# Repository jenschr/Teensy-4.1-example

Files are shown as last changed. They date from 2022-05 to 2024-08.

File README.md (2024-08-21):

# Teensy 4.1 Kicad example project
Kicad files to make a custom Teensy 4.1, based on the official Teensy schematics, but exposing all pins for testing. All the 55 pins except D41 are brought out for testing. I'm using a USB Type C receptacle rather than USB Micro / A connectors. Don't forget that you'll need to buy the MKL02Z32VFG4 from PJRC for this to work. Also - be sure to scroll down on the MKL02Z32VFG4 page. There are [lots of important information there](https://www.pjrc.com/store/ic_mkl02_t4.html) on power sequencing and layout.

I'm a consultant based in Oslo/Norway, so [get in touch](https://maketronics.no/about/) if you need custom hardware based on Teensy 4.x.

## Know bugs
This version is tested and works, but the MAX1562 that I used for the USB switch has inverted polarity from what is expected. You can get around this by using the alternate part MAX1563, or something else. Only reason I went with this 4A chip is the parts shortage.

I just removed the chip and soldered bodge-wires to bypass it. This also works, but I guess it then lacks protection. I've tested with keyboard & mouse.

## Features

The board includes the required parts

- MIMXRT1062DVJ6B (Arm Cortex M7 @ 600 Mhz)
- MKL02Z32VFG4 (must be purchased from PJRC)
- W25Q64JVXGIM (8Mb spi Flash)

Optional parts (not in PJRC's design)

- [USB Type C](https://github.com/jenschr/USB-C-Connectors) for power & debug
- USB Type C host port with MAX1562 for power control
- 2.54mm pin header connections for all pins but D41
- JTAG pins broken out (not tested, but there)

Not included (from PJRC's design)
- Extra SpiFlash or PSRAM
- Ethernet

Note: the schematic symbol for the IMXRT1062 chip is really clumsy and makes the schematic more complex than required, but that's what you get if you use SamacSys Library Loader rather than making the symbol yourself.

## Picture
Here's a picture of the boards when I soldered them:

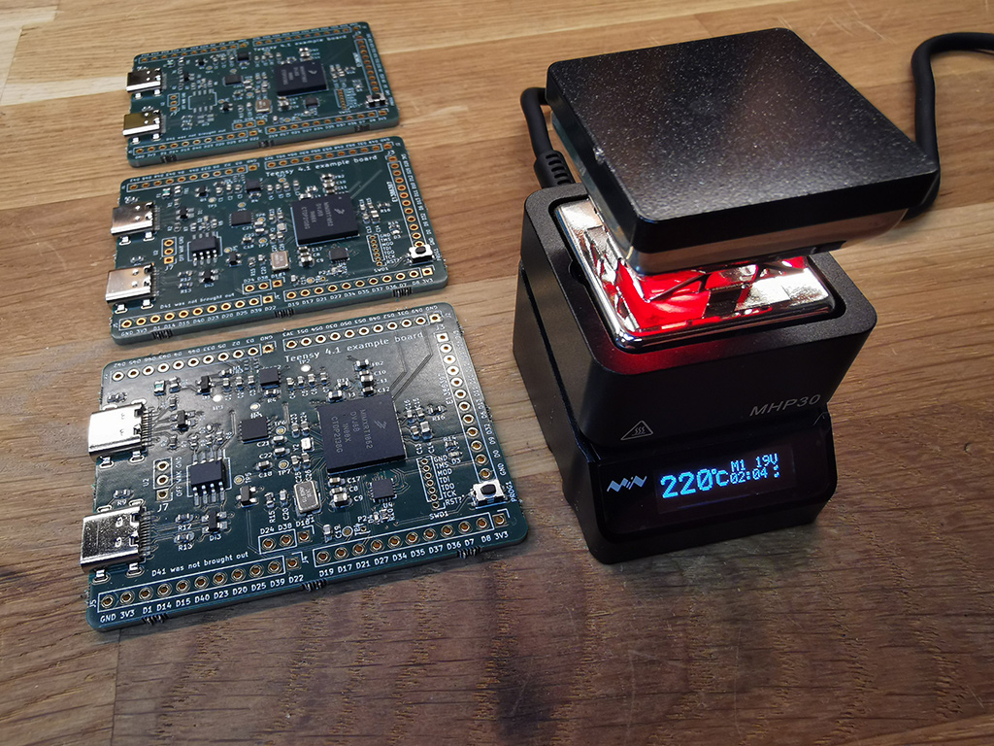
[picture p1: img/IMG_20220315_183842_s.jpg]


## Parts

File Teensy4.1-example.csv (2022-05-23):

Source: | /Volumes/Dropbox/Dropbox/Hardware/Teensy4.1-example/Teensy4.1-example.kicad_sch
Date: | 2022 March 08, Tuesday 17:22:59
Tool: | Eeschema (6.0.1-0)
Generator: | /Applications/KiCad/KiCad.app/Contents/SharedSupport/plugins/bom_csv_grouped_by_value.py
Component Count: | 80
Individual Components:
Item | Qty | Reference(s) | Value | LibPart | Footprint | Datasheet | Description | Height | MFGR | MPN | Manufacturer_Name | Manufacturer_Part_Number | Mouser Part Number | Mouser Price/Stock
 |  | C1 | 0.22uf | Device:C | Capacitor_SMD:C_0603_1608Metric | ~ |  |  | Jellybean (X7R or better) | CC0603KRX7R6BB224
 |  | C2 | 0.22uf | Device:C | Capacitor_SMD:C_0603_1608Metric | ~ |  |  | Jellybean (X7R or better) | CC0603KRX7R6BB224
 |  | C3 | 2.2uf | Device:C | Capacitor_SMD:C_0603_1608Metric | ~ |  |  | Jellybean (X7R or better) | CL10B225KP8NNNC
 |  | C4 | 0.22uf | Device:C | Capacitor_SMD:C_0603_1608Metric | ~ |  |  | Jellybean (X7R or better) | CC0603KRX7R6BB224
 |  | C5 | 10000nf | Device:C | Capacitor_SMD:C_0603_1608Metric | ~ |  |  | Jellybean (X7R or better) | 0603B103K160CT
 |  | C6 | 4.7uf | Device:C | Capacitor_SMD:C_0603_1608Metric | ~ |  |  | Jellybean (X7R or better) | CL10B475KQ8NQNC
 |  | C7 | 2.2uf | Device:C | Capacitor_SMD:C_0603_1608Metric | ~ |  |  | Jellybean (X7R or better) | CL10B225KP8NNNC
 |  | C8 | 0.22uf | Device:C | Capacitor_SMD:C_0603_1608Metric | ~ |  |  | Jellybean (X7R or better) | CC0603KRX7R6BB224
 |  | C9 | 10uf | Device:C | Capacitor_SMD:C_0805_2012Metric | ~ |  |  | Jellybean (X7R or better) | GRM21BR71A106KA73K
 |  | C10 | 0.22uf | Device:C | Capacitor_SMD:C_0603_1608Metric | ~ |  |  | Jellybean (X7R or better) | CC0603KRX7R6BB224
 |  | C11 | 10uf | Device:C | Capacitor_SMD:C_0805_2012Metric | ~ |  |  | Jellybean (X7R or better) | GRM21BR71A106KA73K
 |  | C12 | 4.7uf | Device:C | Capacitor_SMD:C_0603_1608Metric | ~ |  |  | Jellybean (X7R or better) | CL10B475KQ8NQNC
 |  | C13 | 0.22uf | Device:C | Capacitor_SMD:C_0603_1608Metric | ~ |  |  | Jellybean (X7R or better) | CC0603KRX7R6BB224
 |  | C14 | 10uf | Device:C | Capacitor_SMD:C_0805_2012Metric | ~ |  |  | Jellybean (X7R or better) | GRM21BR71A106KA73K
 |  | C15 | 4.7uf | Device:C | Capacitor_SMD:C_0603_1608Metric | ~ |  |  | Jellybean (X7R or better) | CL10B475KQ8NQNC
 |  | C16 | 10000nf | Device:C | Capacitor_SMD:C_0603_1608Metric | ~ |  |  | Jellybean (X7R or better) | 0603B103K160CT
 |  | C17 | 0.22uf | Device:C | Capacitor_SMD:C_0603_1608Metric | ~ |  |  | Jellybean (X7R or better) | CC0603KRX7R6BB224
 |  | C18 | 0.22uf | Device:C | Capacitor_SMD:C_0603_1608Metric | ~ |  |  | Jellybean (X7R or better) | CC0603KRX7R6BB224
 |  | C19 | 10pf | Device:C | Capacitor_SMD:C_0603_1608Metric | ~ |  |  | Jellybean (X7R or better) | CC0603KRX7R6BB224
 |  | C20 | 10pf | Device:C | Capacitor_SMD:C_0603_1608Metric | ~ |  |  | Jellybean (X7R or better) | CC0603KRX7R6BB224
 |  | C21 | 9pf | Device:C | Capacitor_SMD:C_0603_1608Metric | ~ |  |  | Jellybean (X7R or better) | GRM1885C1H9R0DA01D
 |  | C22 | 9pf | Device:C | Capacitor_SMD:C_0603_1608Metric | ~ |  |  | Jellybean (X7R or better) | GRM1885C1H9R0DA01D
 |  | C23 | 0.22uf | Device:C | Capacitor_SMD:C_0603_1608Metric | ~ |  |  | Jellybean (X7R or better) | CC0603KRX7R6BB224
 |  | C24 | 4.7uf | Device:C | Capacitor_SMD:C_0603_1608Metric | ~ |  |  | Jellybean (X7R or better) | CL10B475KQ8NQNC
 |  | C25 | 0.22uf | Device:C | Capacitor_SMD:C_0603_1608Metric | ~ |  |  | Jellybean (X7R or better) | CC0603KRX7R6BB224
 |  | C26 | 4.7uf | Device:C | Capacitor_SMD:C_0603_1608Metric | ~ |  |  | Jellybean (X7R or better) | CL10B475KQ8NQNC
 |  | D1 | SP0503BAHT | Power_Protection:SP0503BAHT | Package_TO_SOT_SMD:SOT-143 | http://www.littelfuse.com/~/media/files/littelfuse/technical%20resources/documents/data%20sheets/sp05xxba.pdf
 |  | D2 | LED | Device:LED | LED_SMD:LED_0402_1005Metric | ~
 |  | D3 | LED | Device:LED | LED_SMD:LED_0402_1005Metric | ~
 |  | D4 | LED | Device:LED | LED_SMD:LED_0402_1005Metric | ~
 |  | D5 | BAT54C | Diode:BAT54C | Package_TO_SOT_SMD:SOT-23 | http://www.diodes.com/_files/datasheets/ds11005.pdf
 |  | Di3 | SP0503BAHT | Power_Protection:SP0503BAHT | Package_TO_SOT_SMD:SOT-143 | http://www.littelfuse.com/~/media/files/littelfuse/technical%20resources/documents/data%20sheets/sp05xxba.pdf
 |  | F1 | Fuse | Device:Fuse | Resistor_SMD:R_0805_2012Metric | ~ |  |  | Bel Fuse Inc | 0ZCK0050FF2E
 |  | FB1 | Ferrite_Bead | Device:Ferrite_Bead | Resistor_SMD:R_0805_2012Metric | ~ |  |  | Taiyo Yuden | FBMH2012HM121-T‎
 |  | FB2 | Ferrite_Bead | Device:Ferrite_Bead | Resistor_SMD:R_0805_2012Metric | ~ |  |  | Taiyo Yuden | FBMH2012HM121-T‎
 |  | IC1 | MIMXRT1062DVJ6B | MIMXRT1062DVJ6B:MIMXRT1062DVJ6B | MIMXRT1062DVJ6B:BGA196C80P14X14_1200X1200X152 | https://www.nxp.com/docs/en/nxp/data-sheets/IMXRT1060CEC.pdf | IC MCU 32BIT EXT MEM 196MAPBGA | 1.52 |  |  | NXP | MIMXRT1062DVJ6B | 771-MIMXRT1062DVJ6B | https://www.mouser.co.uk/ProductDetail/NXP-Semiconductors/MIMXRT1062DVJ6B?qs=BJlw7L4Cy7%252B08A9rbTO5WQ%3D%3D
 |  | J1 | Conn_01x11_Male | Connector:Conn_01x11_Male | Connector_PinHeader_2.54mm:PinHeader_1x11_P2.54mm_Vertical | ~
 |  | J2 | Conn_01x11_Male | Connector:Conn_01x11_Male | Connector_PinHeader_2.54mm:PinHeader_1x11_P2.54mm_Vertical | ~
 |  | J3 | Conn_01x12_Male | Connector:Conn_01x12_Male | Connector_PinHeader_2.54mm:PinHeader_1x12_P2.54mm_Vertical | ~
 |  | J4 | Conn_01x11_Male | Connector:Conn_01x11_Male | Connector_PinHeader_2.54mm:PinHeader_1x11_P2.54mm_Vertical | ~
 |  | J5 | Conn_01x11_Male | Connector:Conn_01x11_Male | Connector_PinHeader_2.54mm:PinHeader_1x11_P2.54mm_Vertical | ~
 |  | J6 | Conn_01x03_Male | Connector:Conn_01x03_Male | Connector_PinHeader_2.54mm:PinHeader_1x03_P2.54mm_Vertical | ~
 |  | J7 | Conn_01x03_Male | Connector:Conn_01x03_Male | Connector_PinHeader_2.54mm:PinHeader_1x03_P2.54mm_Vertical | ~
 |  | L1 | 4.7uH | Device:L | Capacitor_SMD:C_0805_2012Metric | ~ |  |  |  | LQM21PN4R7MGRD
 |  | NCP692 | OnSemi NCP692, fixed version | ToyTronics2:OnSemi NCP692, fixed version | Package_DFN_QFN:DFN-6-1EP_3x3mm_P0.95mm_EP1.7x2.6mm | https://www.onsemi.com/pdf/datasheet/ncp690-d.pdf |  |  | Onsemi | NCP692MN33T2G
 |  | P2 | D26 | Connector:TestPoint | Connector_PinHeader_1.00mm:PinHeader_1x01_P1.00mm_Vertical | ~
 |  | PROG1 | SW_Push | Switch:SW_Push | ToyTronics:KMR241GLFS |  |  |  | C&K | KMR241GLFS
 |  | Q1 | Q_PMOS_GDS | Device:Q_PMOS_GDS | Package_TO_SOT_SMD:SOT-23 | ~
 |  | R1 | 5.1k | Device:R | Resistor_SMD:R_0603_1608Metric | ~ |  |  | Jellybean | RC0603FR-075K1L
 |  | R2 | 5.1k | Device:R | Resistor_SMD:R_0603_1608Metric | ~ |  |  | Jellybean | RC0603FR-075K1L
 |  | R3 | 100k | Device:R | Resistor_SMD:R_0603_1608Metric | ~
 |  | R4 | 100k | Device:R | Resistor_SMD:R_0603_1608Metric | ~
 |  | R5 | 1M | Device:R | Resistor_SMD:R_0603_1608Metric | ~
 |  | R6 | 16k | Device:R | Resistor_SMD:R_0603_1608Metric | ~ |  |  | Jellybean
 |  | R7 | 16k | Device:R | Resistor_SMD:R_0603_1608Metric | ~ |  |  | Jellybean
 |  | R8 | 1k | Device:R | Resistor_SMD:R_0402_1005Metric | ~
 |  | R9 | 1M | Device:R | Resistor_SMD:R_0603_1608Metric | ~
 |  | R10 | 1k | Device:R | Resistor_SMD:R_0402_1005Metric | ~
 |  | R11 | 100k | Device:R | Resistor_SMD:R_0603_1608Metric | ~
 |  | R12 | 56k | Device:R | Resistor_SMD:R_0603_1608Metric | ~ |  |  | Jellybean | RMCF0603FT56K0
 |  | R13 | 56k | Device:R | Resistor_SMD:R_0603_1608Metric | ~ |  |  | Jellybean | RMCF0603FT56K0
 |  | R14 | 1k | Device:R | Resistor_SMD:R_0402_1005Metric | ~
 |  | R15 | 2.2M | Device:R | Resistor_SMD:R_0603_1608Metric | ~
 |  | R16 | 100k | Device:R | Resistor_SMD:R_0603_1608Metric | ~
 |  | SWD1 | SWD | Connector:Conn_01x07_Female | Connector_PinHeader_1.27mm:PinHeader_1x07_P1.27mm_Vertical | ~
 |  | TP1 | TestPoint | Connector:TestPoint | TestPoint:TestPoint_Pad_D1.0mm | ~
 |  | TP2 | TestPoint | Connector:TestPoint | TestPoint:TestPoint_Pad_D1.0mm | ~
 |  | TP3 | TestPoint | Connector:TestPoint | TestPoint:TestPoint_Pad_D1.0mm | ~
 |  | TP4 | TestPoint | Connector:TestPoint | TestPoint:TestPoint_Pad_D1.0mm | ~
 |  | TP5 | TestPoint | Connector:TestPoint | TestPoint:TestPoint_Pad_D1.0mm | ~
 |  | TP6 | TestPoint | Connector:TestPoint | TestPoint:TestPoint_Pad_D1.0mm | ~
 |  | TP7 | TestPoint | Connector:TestPoint | TestPoint:TestPoint_Pad_D1.0mm | ~
 |  | U1 | opto_APA102-2020 | APA102:opto_APA102-2020 | USB-C-Power-tester:APA102-2020
 |  | U2 | MAX1562 | MIMXRT1062DVJ6B:MAX1562 | Package_SO:SO-8_5.3x6.2mm_P1.27mm
 |  | U3 | W25Q64JVXGIM | MIMXRT1062DVJ6B:W25Q64VXGIM | MIMXRT1062DVJ6B:XSON8_4x4mm
 |  | U4 | MKL02Z32VFG4 | MCU_NXP_Kinetis:MKL02Z32VFG4 | Package_DFN_QFN:QFN-16-1EP_3x3mm_P0.5mm_EP1.8x1.8mm | http://www.nxp.com/docs/en/data-sheet/KL02P32M48SF0.pdf |  |  | Supplied by Roest Coffee | Custom firmware part
 |  | USB_DFP1 | USB_C_Receptacle_USB2.0 | simonsen:USB_C_Receptacle_USB2.0_NOPOW | USB-C-Power-tester:TYPE-C-31-M-14 | https://www.usb.org/sites/default/files/documents/usb_type-c.zip
 |  | USB_UFP1 | USB_C_Receptacle_USB2.0 | Connector:USB_C_Receptacle_USB2.0 | USB-C-Power-tester:TYPE-C-31-M-14 | https://www.usb.org/sites/default/files/documents/usb_type-c.zip
 |  | Y1 | Crystal_GND23 | Device:Crystal_GND24 | Crystal:Crystal_SMD_Abracon_ABM3B-4Pin_5.0x3.2mm | ~
 |  | Y2 | Crystal | Device:Crystal | Crystal:Crystal_SMD_2012-2Pin_2.0x1.2mm | ~ |  |  | Abracon | ABS06-32.768KHZ-9-1-T
Collated Components:
Item | Qty | Reference(s) | Value | LibPart | Footprint | Datasheet | Description | Height | MFGR | MPN | Manufacturer_Name | Manufacturer_Part_Number | Mouser Part Number | Mouser Price/Stock
1 | 10 | C1, C2, C4, C8, C10, C13, C17, C18, C23, C25 | 0.22uf | Device:C | Capacitor_SMD:C_0603_1608Metric | ~ |  |  | Jellybean (X7R or better) | CC0603KRX7R6BB224
2 | 2 | C3, C7 | 2.2uf | Device:C | Capacitor_SMD:C_0603_1608Metric | ~ |  |  | Jellybean (X7R or better) | CL10B225KP8NNNC
3 | 2 | C5, C16 | 10000nf | Device:C | Capacitor_SMD:C_0603_1608Metric | ~ |  |  | Jellybean (X7R or better) | 0603B103K160CT
4 | 5 | C6, C12, C15, C24, C26 | 4.7uf | Device:C | Capacitor_SMD:C_0603_1608Metric | ~ |  |  | Jellybean (X7R or better) | CL10B475KQ8NQNC
5 | 3 | C9, C11, C14 | 10uf | Device:C | Capacitor_SMD:C_0805_2012Metric | ~ |  |  | Jellybean (X7R or better) | GRM21BR71A106KA73K
6 | 2 | C19, C20 | 10pf | Device:C | Capacitor_SMD:C_0603_1608Metric | ~ |  |  | Jellybean (X7R or better) | CC0603KRX7R6BB224
7 | 2 | C21, C22 | 9pf | Device:C | Capacitor_SMD:C_0603_1608Metric | ~ |  |  | Jellybean (X7R or better) | GRM1885C1H9R0DA01D
8 | 2 | D1, Di3 | SP0503BAHT | Power_Protection:SP0503BAHT | Package_TO_SOT_SMD:SOT-143 | http://www.littelfuse.com/~/media/files/littelfuse/technical%20resources/documents/data%20sheets/sp05xxba.pdf
9 | 3 | D2, D3, D4 | LED | Device:LED | LED_SMD:LED_0402_1005Metric | ~
10 | 1 | D5 | BAT54C | Diode:BAT54C | Package_TO_SOT_SMD:SOT-23 | http://www.diodes.com/_files/datasheets/ds11005.pdf
11 | 1 | F1 | Fuse | Device:Fuse | Resistor_SMD:R_0805_2012Metric | ~ |  |  | Bel Fuse Inc | 0ZCK0050FF2E
12 | 2 | FB1, FB2 | Ferrite_Bead | Device:Ferrite_Bead | Resistor_SMD:R_0805_2012Metric | ~ |  |  | Taiyo Yuden | FBMH2012HM121-T‎
13 | 1 | IC1 | MIMXRT1062DVJ6B | MIMXRT1062DVJ6B:MIMXRT1062DVJ6B | MIMXRT1062DVJ6B:BGA196C80P14X14_1200X1200X152 | https://www.nxp.com/docs/en/nxp/data-sheets/IMXRT1060CEC.pdf | IC MCU 32BIT EXT MEM 196MAPBGA | 1.52 |  |  | NXP | MIMXRT1062DVJ6B | 771-MIMXRT1062DVJ6B | https://www.mouser.co.uk/ProductDetail/NXP-Semiconductors/MIMXRT1062DVJ6B?qs=BJlw7L4Cy7%252B08A9rbTO5WQ%3D%3D
14 | 4 | J1, J2, J4, J5 | Conn_01x11_Male | Connector:Conn_01x11_Male | Connector_PinHeader_2.54mm:PinHeader_1x11_P2.54mm_Vertical | ~
15 | 1 | J3 | Conn_01x12_Male | Connector:Conn_01x12_Male | Connector_PinHeader_2.54mm:PinHeader_1x12_P2.54mm_Vertical | ~
16 | 2 | J6, J7 | Conn_01x03_Male | Connector:Conn_01x03_Male | Connector_PinHeader_2.54mm:PinHeader_1x03_P2.54mm_Vertical | ~
17 | 1 | L1 | 4.7uH | Device:L | Capacitor_SMD:C_0805_2012Metric | ~ |  |  |  | LQM21PN4R7MGRD
18 | 1 | NCP692 | OnSemi NCP692, fixed version | ToyTronics2:OnSemi NCP692, fixed version | Package_DFN_QFN:DFN-6-1EP_3x3mm_P0.95mm_EP1.7x2.6mm | https://www.onsemi.com/pdf/datasheet/ncp690-d.pdf |  |  | Onsemi | NCP692MN33T2G
19 | 1 | P2 | D26 | Connector:TestPoint | Connector_PinHeader_1.00mm:PinHeader_1x01_P1.00mm_Vertical | ~
20 | 1 | PROG1 | SW_Push | Switch:SW_Push | ToyTronics:KMR241GLFS |  |  |  | C&K | KMR241GLFS
21 | 1 | Q1 | Q_PMOS_GDS | Device:Q_PMOS_GDS | Package_TO_SOT_SMD:SOT-23 | ~
22 | 2 | R1, R2 | 5.1k | Device:R | Resistor_SMD:R_0603_1608Metric | ~ |  |  | Jellybean | RC0603FR-075K1L
23 | 4 | R3, R4, R11, R16 | 100k | Device:R | Resistor_SMD:R_0603_1608Metric | ~
24 | 2 | R5, R9 | 1M | Device:R | Resistor_SMD:R_0603_1608Metric | ~
25 | 2 | R6, R7 | 16k | Device:R | Resistor_SMD:R_0603_1608Metric | ~ |  |  | Jellybean
26 | 3 | R8, R10, R14 | 1k | Device:R | Resistor_SMD:R_0402_1005Metric | ~
27 | 2 | R12, R13 | 56k | Device:R | Resistor_SMD:R_0603_1608Metric | ~ |  |  | Jellybean | RMCF0603FT56K0
28 | 1 | R15 | 2.2M | Device:R | Resistor_SMD:R_0603_1608Metric | ~
29 | 1 | SWD1 | SWD | Connector:Conn_01x07_Female | Connector_PinHeader_1.27mm:PinHeader_1x07_P1.27mm_Vertical | ~
30 | 7 | TP1, TP2, TP3, TP4, TP5, TP6, TP7 | TestPoint | Connector:TestPoint | TestPoint:TestPoint_Pad_D1.0mm | ~
31 | 1 | U1 | opto_APA102-2020 | APA102:opto_APA102-2020 | USB-C-Power-tester:APA102-2020
32 | 1 | U2 | MAX1562 | MIMXRT1062DVJ6B:MAX1562 | Package_SO:SO-8_5.3x6.2mm_P1.27mm
33 | 1 | U3 | W25Q64JVXGIM | MIMXRT1062DVJ6B:W25Q64VXGIM | MIMXRT1062DVJ6B:XSON8_4x4mm
34 | 1 | U4 | MKL02Z32VFG4 | MCU_NXP_Kinetis:MKL02Z32VFG4 | Package_DFN_QFN:QFN-16-1EP_3x3mm_P0.5mm_EP1.8x1.8mm | http://www.nxp.com/docs/en/data-sheet/KL02P32M48SF0.pdf |  |  | Supplied by Roest Coffee | Custom firmware part
35 | 1 | USB_DFP1 | USB_C_Receptacle_USB2.0 | simonsen:USB_C_Receptacle_USB2.0_NOPOW | USB-C-Power-tester:TYPE-C-31-M-14 | https://www.usb.org/sites/default/files/documents/usb_type-c.zip
36 | 1 | USB_UFP1 | USB_C_Receptacle_USB2.0 | Connector:USB_C_Receptacle_USB2.0 | USB-C-Power-tester:TYPE-C-31-M-14 | https://www.usb.org/sites/default/files/documents/usb_type-c.zip
37 | 1 | Y1 | Crystal_GND23 | Device:Crystal_GND24 | Crystal:Crystal_SMD_Abracon_ABM3B-4Pin_5.0x3.2mm | ~
38 | 1 | Y2 | Crystal | Device:Crystal | Crystal:Crystal_SMD_2012-2Pin_2.0x1.2mm | ~ |  |  | Abracon | ABS06-32.768KHZ-9-1-T

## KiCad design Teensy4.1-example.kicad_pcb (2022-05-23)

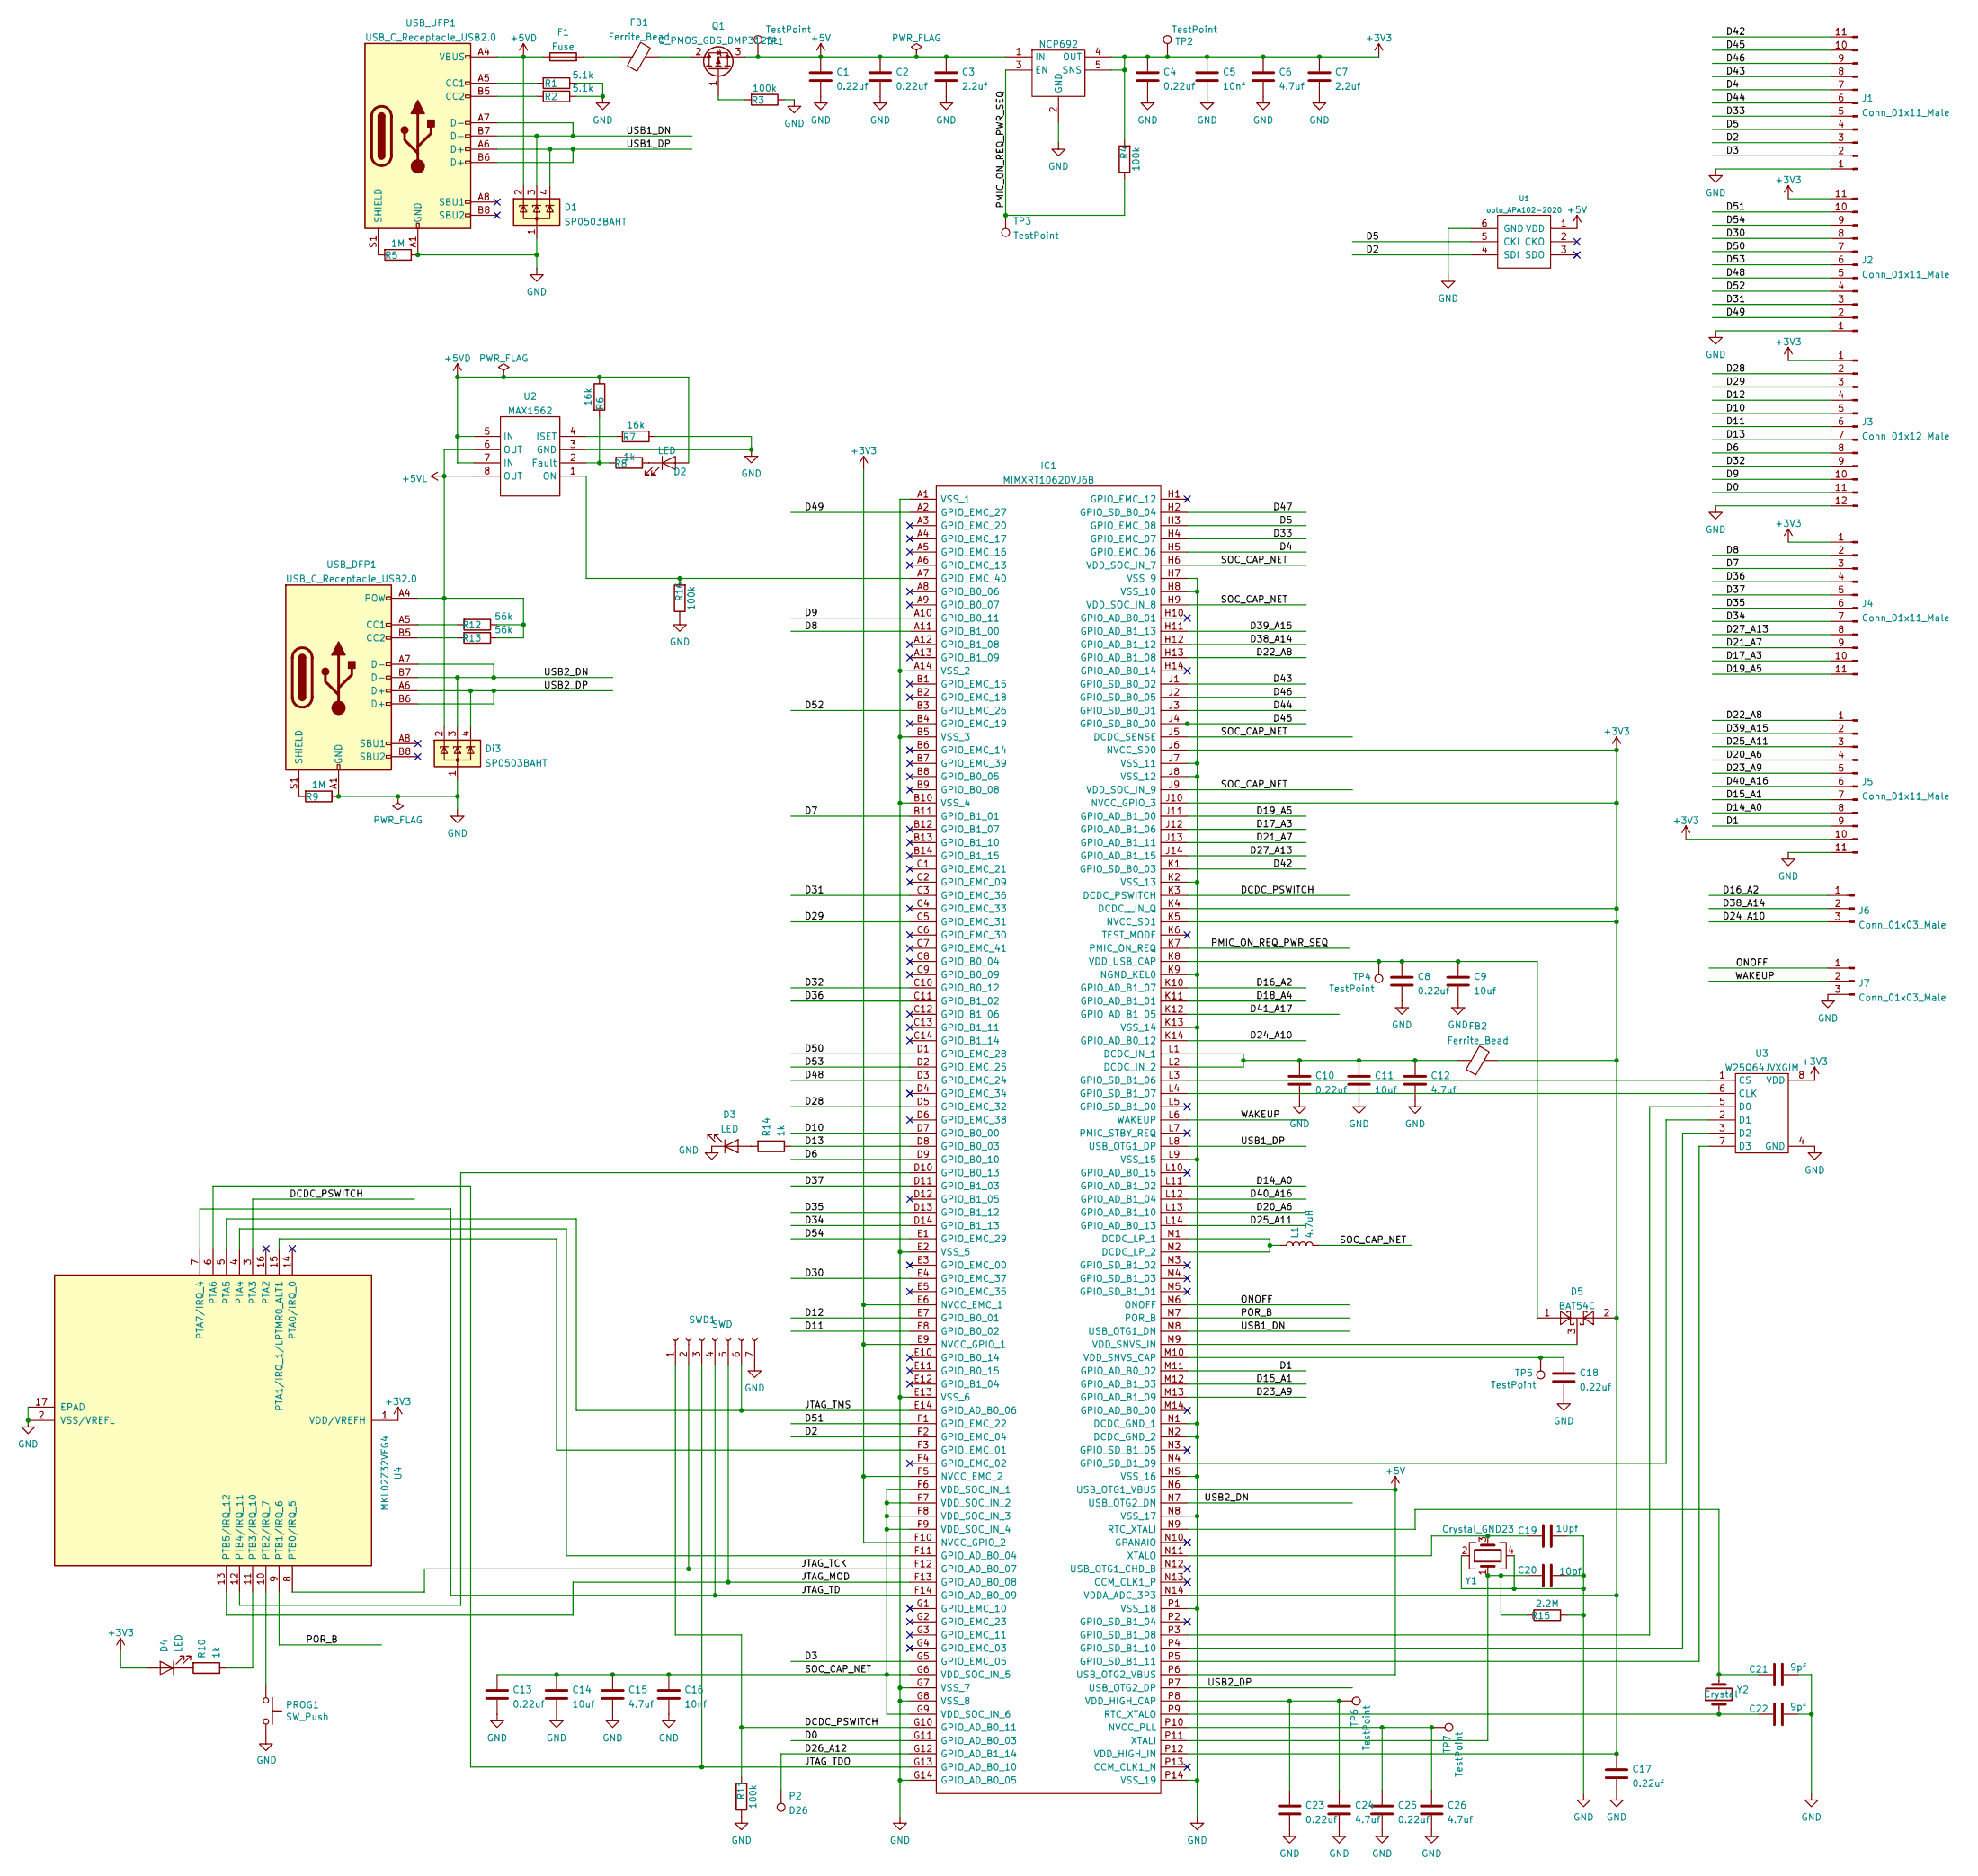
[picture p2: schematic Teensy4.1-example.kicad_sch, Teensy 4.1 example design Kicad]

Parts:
C1, C2, C4, C8, C10, C13, C17, C18, C23, C25: 0.22uf; C_0603_1608Metric; MPN CC0603KRX7R6BB224
C3, C7: 2.2uf; C_0603_1608Metric; MPN CL10B225KP8NNNC
C5, C16: 10nf; C_0603_1608Metric; MPN 0603B103K160CT
C6, C12, C15, C24, C26: 4.7uf; C_0603_1608Metric; MPN CL10B475KQ8NQNC
C9, C11, C14: 10uf; C_0805_2012Metric; MPN GRM21BR71A106KA73K
C19, C20: 10pf; C_0603_1608Metric; MPN CC0603KRX7R6BB224
C21, C22: 9pf; C_0603_1608Metric; MPN GRM1885C1H9R0DA01D
D1: SP0503BAHT; SOT-143
D2, D3, D4: LED; LED_0402_1005Metric
D5: BAT54C; SOT-23
Di3: SP0503BAHT; SOT-143
F1: Fuse; R_0805_2012Metric; MPN 0ZCK0050FF2E
FB1, FB2: Ferrite_Bead; R_0805_2012Metric; MPN FBMH2012HM121-T‎
IC1: MIMXRT1062DVJ6B; BGA196C80P14X14_1200X1200X152; Mouser Part Number 771-MIMXRT1062DVJ6B
J1, J2, J4, J5: Conn_01x11_Male; PinHeader_1x11_P2.54mm_Vertical
J3: Conn_01x12_Male; PinHeader_1x12_P2.54mm_Vertical
J6, J7: Conn_01x03_Male; PinHeader_1x03_P2.54mm_Vertical
L1: 4.7uH; C_0805_2012Metric; MPN LQM21PN4R7MGRD
NCP692: OnSemi NCP692, fixed version; DFN-6-1EP_3x3mm_P0.95mm_EP1.7x2.6mm; MPN NCP692MN33T2G
P2: D26; PinHeader_1x01_P1.00mm_Vertical
PROG1: SW_Push; KMR241GLFS; MPN KMR241GLFS
Q1: Q_PMOS_GDS_DMP3125L; SOT-23
R1, R2: 5.1k; R_0603_1608Metric; MPN RC0603FR-075K1L
R3, R4, R11, R16: 100k; R_0603_1608Metric
R5, R9: 1M; R_0603_1608Metric
R6, R7: 16k; R_0603_1608Metric
R8, R10, R14: 1k; R_0402_1005Metric
R12, R13: 56k; R_0603_1608Metric; MPN RMCF0603FT56K0
R15: 2.2M; R_0603_1608Metric
SWD1: SWD; PinHeader_1x07_P1.27mm_Vertical
TP1, TP2, TP3, TP4, TP5, TP6, TP7: TestPoint; TestPoint_Pad_D1.0mm
U1: opto_APA102-2020; APA102-2020
U2: MAX1562; SO-8_3.9x4.9mm_P1.27mm
U3: W25Q64JVXGIM; XSON8_4x4mm
U4: MKL02Z32VFG4; QFN-16-1EP_3x3mm_P0.5mm_EP1.8x1.8mm; MPN Custom firmware part
USB_DFP1: USB_C_Receptacle_USB2.0; TYPE-C-31-M-14
USB_UFP1: USB_C_Receptacle_USB2.0; TYPE-C-31-M-14
Y1: Crystal_GND23; Crystal_SMD_Abracon_ABM3B-4Pin_5.0x3.2mm
Y2: Crystal; Crystal_SMD_2012-2Pin_2.0x1.2mm; MPN ABS06-32.768KHZ-9-1-T

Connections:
+3V3: C4.1, C5.1, C6.1, C7.1, C17.1, D4.2 (A), D5.2, FB2.2, IC1.E6 (NVCC_EMC_1), IC1.E9 (NVCC_GPIO_1), IC1.F5 (NVCC_EMC_2), IC1.F10 (NVCC_GPIO_2), IC1.J6 (NVCC_SD0), IC1.J10 (NVCC_GPIO_3), IC1.K4 (DCDC__IN_Q), IC1.K5 (NVCC_SD1), IC1.N14 (VDDA_ADC_3P3), IC1.P12 (VDD_HIGH_IN), J2.11, J3.1, J4.1, J5.10, NCP692.4 (OUT), NCP692.5 (SNS), R4.2, TP2.1, U3.8 (VDD), U4.1 (VDD/VREFH)
+5V: C1.1, C2.1, C3.1, IC1.N6 (USB_OTG1_VBUS), IC1.P6 (USB_OTG2_VBUS), NCP692.1 (IN), NCP692.6 (IN), Q1.3 (S), TP1.1, U1.1 (VDD)
+5VD: D1.2 (K), D2.2 (A), F1.1, R6.1, U2.5 (IN), U2.7 (IN), USB_UFP1.A4 (VBUS), USB_UFP1.A9 (VBUS), USB_UFP1.B4 (VBUS), USB_UFP1.B9 (VBUS)
+5VL: Di3.2 (K), R12.1, R13.1, U2.6 (OUT), U2.8 (OUT), USB_DFP1.A4 (POW), USB_DFP1.A9 (POW), USB_DFP1.B4 (POW), USB_DFP1.B9 (POW)
/D0: IC1.G11 (GPIO_AD_B0_03), J3.11
/D1: IC1.M11 (GPIO_AD_B0_02), J5.9
/D2: IC1.F2 (GPIO_EMC_04), J1.3, U1.4 (SDI)
/D3: IC1.G5 (GPIO_EMC_05), J1.2
/D4: IC1.H5 (GPIO_EMC_06), J1.7
/D5: IC1.H3 (GPIO_EMC_08), J1.4, U1.5 (CKI)
/D6: IC1.D9 (GPIO_B0_10), J3.8
/D7: IC1.B11 (GPIO_B1_01), J4.3
/D8: IC1.A11 (GPIO_B1_00), J4.2
/D9: IC1.A10 (GPIO_B0_11), J3.10
/D10: IC1.D7 (GPIO_B0_00), J3.5
/D11: IC1.E8 (GPIO_B0_02), J3.6
/D12: IC1.E7 (GPIO_B0_01), J3.4
/D13: IC1.D8 (GPIO_B0_03), J3.7, R14.1
/D14_A0: IC1.L11 (GPIO_AD_B1_02), J5.8
/D15_A1: IC1.M12 (GPIO_AD_B1_03), J5.7
/D16_A2: IC1.K10 (GPIO_AD_B1_07), J6.1
/D17_A3: IC1.J12 (GPIO_AD_B1_06), J4.10
/D18_A4: IC1.K11 (GPIO_AD_B1_01)
/D19_A5: IC1.J11 (GPIO_AD_B1_00), J4.11
/D20_A6: IC1.L13 (GPIO_AD_B1_10), J5.4
/D21_A7: IC1.J13 (GPIO_AD_B1_11), J4.9
/D22_A8: IC1.H13 (GPIO_AD_B1_08), J5.1
/D23_A9: IC1.M13 (GPIO_AD_B1_09), J5.5
/D24_A10: IC1.K14 (GPIO_AD_B0_12), J6.3
/D25_A11: IC1.L14 (GPIO_AD_B0_13), J5.3
/D26_A12: IC1.G12 (GPIO_AD_B1_14), P2.1
/D27_A13: IC1.J14 (GPIO_AD_B1_15), J4.8
/D28: IC1.D5 (GPIO_EMC_32), J3.2
/D29: IC1.C5 (GPIO_EMC_31), J3.3
/D30: IC1.E4 (GPIO_EMC_37), J2.8
/D31: IC1.C3 (GPIO_EMC_36), J2.3
/D32: IC1.C10 (GPIO_B0_12), J3.9
/D33: IC1.H4 (GPIO_EMC_07), J1.5
/D34: IC1.D14 (GPIO_B1_13), J4.7
/D35: IC1.D13 (GPIO_B1_12), J4.6
/D36: IC1.C11 (GPIO_B1_02), J4.4
/D37: IC1.D11 (GPIO_B1_03), J4.5
/D38_A14: IC1.H12 (GPIO_AD_B1_12), J6.2
/D39_A15: IC1.H11 (GPIO_AD_B1_13), J5.2
/D40_A16: IC1.L12 (GPIO_AD_B1_04), J5.6
/D41_A17: IC1.K12 (GPIO_AD_B1_05)
/D42: IC1.K1 (GPIO_SD_B0_03), J1.11
/D43: IC1.J1 (GPIO_SD_B0_02), J1.8
/D44: IC1.J3 (GPIO_SD_B0_01), J1.6
/D45: IC1.J4 (GPIO_SD_B0_00), J1.10
/D46: IC1.J2 (GPIO_SD_B0_05), J1.9
/D47: IC1.H2 (GPIO_SD_B0_04)
/D48: IC1.D3 (GPIO_EMC_24), J2.5
/D49: IC1.A2 (GPIO_EMC_27), J2.2
/D50: IC1.D1 (GPIO_EMC_28), J2.7
/D51: IC1.F1 (GPIO_EMC_22), J2.10
/D52: IC1.B3 (GPIO_EMC_26), J2.4
/D53: IC1.D2 (GPIO_EMC_25), J2.6
/D54: IC1.E1 (GPIO_EMC_29), J2.9
/DCDC_PSWITCH: IC1.G10 (GPIO_AD_B0_11), IC1.K3 (DCDC_PSWITCH), R11.2, SWD1.1, U4.3 (PTA3)
/JTAG_MOD: IC1.F13 (GPIO_AD_B0_08), SWD1.5, U4.13 (PTB5/IRQ_12)
/JTAG_TCK: IC1.F12 (GPIO_AD_B0_07), SWD1.2, U4.8 (PTB0/IRQ_5)
/JTAG_TDI: IC1.F14 (GPIO_AD_B0_09), SWD1.4, U4.7 (PTA7/IRQ_4)
/JTAG_TDO: IC1.G13 (GPIO_AD_B0_10), SWD1.3, U4.6 (PTA6)
/JTAG_TMS: IC1.E14 (GPIO_AD_B0_06), SWD1.6, U4.5 (PTA5)
/ONOFF: IC1.M6 (ONOFF), J7.1
/PMIC_ON_REQ_PWR_SEQ: IC1.K7 (PMIC_ON_REQ), NCP692.3 (EN), R4.1, TP3.1
/POR_B: IC1.M7 (POR_B), U4.9 (PTB1/IRQ_6)
/SOC_CAP_NET: C13.1, C14.1, C15.1, C16.1, IC1.F6 (VDD_SOC_IN_1), IC1.F7 (VDD_SOC_IN_2), IC1.F8 (VDD_SOC_IN_3), IC1.F9 (VDD_SOC_IN_4), IC1.G6 (VDD_SOC_IN_5), IC1.G9 (VDD_SOC_IN_6), IC1.H6 (VDD_SOC_IN_7), IC1.H9 (VDD_SOC_IN_8), IC1.J5 (DCDC_SENSE), IC1.J9 (VDD_SOC_IN_9), L1.2
/USB1_DN: D1.3 (K), IC1.M8 (USB_OTG1_DN), USB_UFP1.A7 (D-), USB_UFP1.B7 (D-)
/USB1_DP: D1.4 (K), IC1.L8 (USB_OTG1_DP), USB_UFP1.A6 (D+), USB_UFP1.B6 (D+)
/USB2_DN: Di3.3 (K), IC1.N7 (USB_OTG2_DN), USB_DFP1.A7 (D-), USB_DFP1.B7 (D-)
/USB2_DP: Di3.4 (K), IC1.P7 (USB_OTG2_DP), USB_DFP1.A6 (D+), USB_DFP1.B6 (D+)
/WAKEUP: IC1.L6 (WAKEUP), J7.2
GND: C1.2, C2.2, C3.2, C4.2, C5.2, C6.2, C7.2, C8.2, C9.2, C10.2, C11.2, C12.2, C13.2, C14.2, C15.2, C16.2, C17.2, C18.2, C19.2, C20.2, C21.2, C22.2, C23.2, C24.2, C25.2, C26.2, D1.1 (A), D3.1 (K), Di3.1 (A), IC1.A1 (VSS_1), IC1.A14 (VSS_2), IC1.B5 (VSS_3), IC1.B10 (VSS_4), IC1.E2 (VSS_5), IC1.E13 (VSS_6), IC1.G7 (VSS_7), IC1.G8 (VSS_8), IC1.G14 (GPIO_AD_B0_05), IC1.H7 (VSS_9), IC1.H8 (VSS_10), IC1.J7 (VSS_11), IC1.J8 (VSS_12), IC1.K2 (VSS_13), IC1.K9 (NGND_KEL0), IC1.K13 (VSS_14), IC1.L9 (VSS_15), IC1.N1 (DCDC_GND_1), IC1.N2 (DCDC_GND_2), IC1.N5 (VSS_16), IC1.N8 (VSS_17), IC1.P1 (VSS_18), IC1.P14 (VSS_19), J1.1, J2.1, J3.12, J5.11, J7.3, NCP692.2 (GND), NCP692.7 (GND), PROG1.2, R1.1, R2.1, R3.1, R5.1, R7.1, R9.1, R11.1, R15.1, R16.1, SWD1.7, U1.6 (GND), U2.3 (GND), U3.4 (GND), U4.2 (VSS/VREFL), U4.17 (EPAD), USB_DFP1.A1 (GND), USB_DFP1.A12 (GND), USB_DFP1.B1 (GND), USB_DFP1.B12 (GND), USB_UFP1.A1 (GND), USB_UFP1.A12 (GND), USB_UFP1.B1 (GND), USB_UFP1.B12 (GND), Y1.2, Y1.4
unnamed: C8.1, C9.1, D5.1, IC1.K8 (VDD_USB_CAP), TP4.1
unnamed: C10.1, C11.1, C12.1, FB2.1, IC1.L1 (DCDC_IN_1), IC1.L2 (DCDC_IN_2)
unnamed: C18.1, IC1.M10 (VDD_SNVS_CAP), TP5.1
unnamed: C19.1, IC1.N11 (XTALO), Y1.3
unnamed: C20.1, IC1.P11 (XTALI), R15.2, Y1.1
unnamed: C21.1, IC1.N9 (RTC_XTALI), Y2.2
unnamed: C22.1, IC1.P9 (RTC_XTALO), Y2.1
unnamed: C23.1, C24.1, IC1.P8 (VDD_HIGH_CAP), TP6.1
unnamed: C25.1, C26.1, IC1.P10 (NVCC_PLL), TP7.1
unnamed: D2.1 (K), R8.1
unnamed: D3.2 (A), R14.2
unnamed: D4.1 (K), R10.2
unnamed: D5.3, IC1.M9 (VDD_SNVS_IN)
unnamed: F1.2, FB1.1
unnamed: FB1.2, Q1.2 (D)
unnamed: IC1.A7 (GPIO_EMC_40), R16.2, U2.1 (ON)
unnamed: IC1.D10 (GPIO_B0_13), U4.12 (PTB4/IRQ_11)
unnamed: IC1.F3 (GPIO_EMC_01), U4.15 (PTA1/IRQ_1/LPTMR0_ALT1)
unnamed: IC1.F11 (GPIO_AD_B0_04), U4.4 (PTA4)
unnamed: IC1.L3 (GPIO_SD_B1_06), U3.1 (CS)
unnamed: IC1.L4 (GPIO_SD_B1_07), U3.6 (CLK)
unnamed: IC1.M1 (DCDC_LP_1), IC1.M2 (DCDC_LP_2), L1.1
unnamed: IC1.N4 (GPIO_SD_B1_09), U3.2 (D1)
unnamed: IC1.P3 (GPIO_SD_B1_08), U3.5 (D0)
unnamed: IC1.P4 (GPIO_SD_B1_10), U3.3 (D2)
unnamed: IC1.P5 (GPIO_SD_B1_11), U3.7 (D3)
unnamed: PROG1.1, U4.10 (PTB2/IRQ_7)
unnamed: Q1.1 (G), R3.2
unnamed: R1.2, USB_UFP1.A5 (CC1)
unnamed: R2.2, USB_UFP1.B5 (CC2)
unnamed: R5.2, USB_UFP1.S1 (SHIELD)
unnamed: R6.2, R8.2, U2.2 (Fault)
unnamed: R7.2, U2.4 (ISET)
unnamed: R9.2, USB_DFP1.S1 (SHIELD)
unnamed: R10.1, U4.11 (PTB3/IRQ_10)
unnamed: R12.2, USB_DFP1.A5 (CC1)
unnamed: R13.2, USB_DFP1.B5 (CC2)

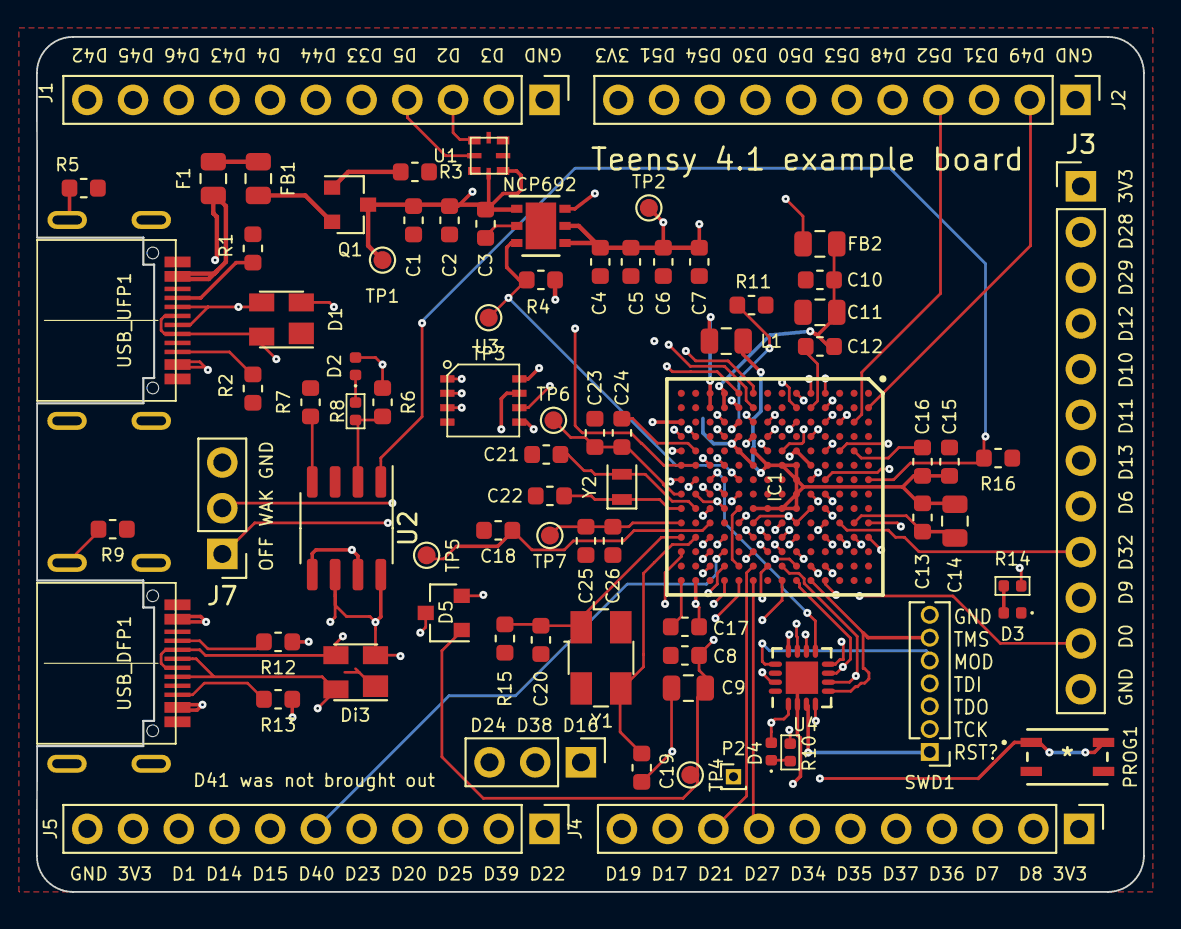
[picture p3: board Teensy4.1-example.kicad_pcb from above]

Board: 4 copper layers, 61.5 x 47.5 mm, 80 parts (0 on the bottom side), 109 nets.

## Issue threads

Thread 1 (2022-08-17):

Schematic rework

fabianmuehlberger, 2022-08-17:
Hi,

I noticed your project and I'm currently working on a rework of your not-so-ideal schematic and RT1062 Symbol.
It's far from done, but this is what I got so far. https://github.com/fabianmuehlberger/Teensy-4.1-example

If you are interested in a merge, let me know.

Best Fabian

jenschr, 2022-08-17:
Hi Fabian,
Sure! Did you test your version yet?

J

On Wed, Aug 17, 2022 at 4:09 PM fabianmuehlberger ***@***.***>
wrote:

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

--
Vennlig hilsen
Jens Chr Brynildsen

mob +47 90691786
www.flashgamer.com

fabianmuehlberger, 2022-08-17:
I just did the rework today. I haven't run any tests on it
The footprint didn't link from your fork, so this will be the first thing I check. Have you made your own footprint or where did you get it from? If it is well done I would use it too.

jenschr, 2022-08-17:
Heya,
I can't remember exactly, but I'm quite sure that I used the generator
built into Kicad. I've done 5 different boards using this chip & setup by
now, so I'm quite confident that it works as intended.

J

On Wed, Aug 17, 2022 at 4:50 PM fabianmuehlberger ***@***.***>
wrote:

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

--
Vennlig hilsen
Jens Chr Brynildsen

mob +47 90691786
www.flashgamer.com

jenschr, 2022-09-14:
@fabianmuehlberger got your board tested and verified now? If so, I'd love to include it?

fabianmuehlberger, 2022-09-14:
not finished, I think I'm pretty much done with the USB and power section, divided the schematic into hierarchical sheets and drew a few nets new.

You might want to check it though, its basically a new schematic

jenschr, 2023-02-16:
Heya. I just had a look now. Looks like you never finished? At least, I can't see any power pins to the chip? ;-)

Closed 2023-04-07.

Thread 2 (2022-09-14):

Add Ethernet Support

sdrabb, 2022-09-14:
can we collaborate to start integrating some peripheral to the board? why not eth for example?
Thanks @jenschr

jenschr, 2022-09-14:
@sdrabb Hi. This board isn't really meant to be used as is. It's more like a starting point for others. Adding Ethernet is not hard though. Just follow the schematic and add a similar ETH plug as PJRC is using? https://www.pjrc.com/store/j1b1211ccd.pdf Then you lay that out in a board that is better suited for your purpose?

sdrabb, 2022-09-15:
great, thanks!

Closed 2022-09-15.

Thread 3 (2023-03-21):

D41

Fluxanode, 2023-03-21:
You say D41 was not brought out.  What is D41, I can't find that pin anyway?

jenschr, 2023-03-22:
D41 refers to the Teensy pin marked as just 41 in the official pinout https://www.pjrc.com/teensy/pinout.html

Fluxanode, 2023-03-22:
Thanks.  Why did you leave it out of your design?

jenschr, 2023-03-23:
Lack of space 😉

Closed 2023-03-23.

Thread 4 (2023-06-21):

Any reason why SD not included?

FuzzyWobble, 2023-06-21:
Thanks for this great project, just curious why SD was not included?

jenschr, 2023-07-18:
Heya. Just that I dosent need it for the project I made this test card for. Should be easy to add by referencing PJRC’s schematics 😉

Closed 2023-07-18.

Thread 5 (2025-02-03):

Not a bug, I want to contact you for a custom PCB with a teensy 4.0.

propeller3D, 2025-02-03:
Sorry for writing here I don't have your email address. I have a project that has a PCB with a teensy 4 soldered to it. I would like to integrate the teensy 4 into the PCB and also make the code safe from copying etc. so I can send to people to beta test without revealing the magic inside.  Th reason I need the integrated Teensy is for the USB. The project is a very advanced electronic drum and I need to break out a solid USB connection that will be mounted outside the drum.

Could I commission you to do it for me?

Let me know your email address or contact info to discuss further.

jenschr, 2025-02-03:
Hi. Feel free to contact me via the contact form at https://maketronics.no/support/ or use "jenschr" at gmail

jenschr, 2025-02-03:
And sure - this is what I do as a consultant ;-)

Closed 2025-02-03.

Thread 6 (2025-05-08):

Bootloader communicating with serial debug

Wierdwizard2587, 2025-05-08:
[My Custom Teensy 4.1](https://github.com/Wierdwizard2587/Custom-Teensy-4.1-PCB-Design) which is based upon this design greatly, keeps getting error code 43 in my device manager and is getting a descripter fail. would you be able to explain what I should be expecting to see on the JTAG breakout pins for the bootloader?

 I believe TDO and TDI are responsible for usb comms to the bootloader but i am not sure. i cant rule out my PCB layout just yet for it, although at this stage its not given me any reason to doubt its efficacy for serial comms. The only difference in my design against yours is ive included an SD card slot, Ethernet and external ram. Thankyou for any insight you may be able to provide.

regards,
Alex

Wierdwizard2587, 2025-05-10:
turns out the ESD diodes were rated for USB 1.1 not USB 2.0 so when they were taken off it worked fine. i used the same ones that you utilised, but just for reference should anyone come across the same issue.

jenschr, 2025-05-10:
@Wierdwizard2587 Sorry for not following up on this, but glad you found it out!
I've also had similar problems with ESD diodes. The ESD diode I'm currently using on these designs is the SP3003-02JTG from Littelfuse Inc. It seems to have less problems. Next week I'm sending boards with this for destructive ESD testing as part of a CE approval.

Closed 2025-05-10.

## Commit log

2022-05-23 First version on Github. Be sure to read Known Bugs section before making this board
    [Teensy4.1-example.csv, Teensy4.1-example.kicad_pcb, Teensy4.1-example.kicad_sch]
2022-05-23 added picture of boards
2025-01-02 Update MPN for CAP
    [Teensy4.1-example.kicad_sch]

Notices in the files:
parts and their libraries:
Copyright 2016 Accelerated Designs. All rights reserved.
